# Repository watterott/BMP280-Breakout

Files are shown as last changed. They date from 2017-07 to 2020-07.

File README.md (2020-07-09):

# BMP280-Breakout
Breakout with BMP280 Digital Absolute Barometric Pressure Sensor from Bosch Sensortec.

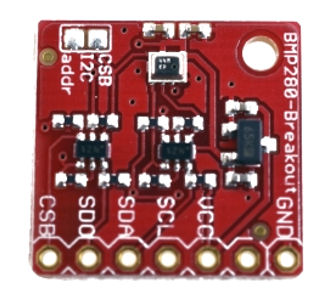
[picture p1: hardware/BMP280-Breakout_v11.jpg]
BMP280-Breakout


* [Bosch BMP280](https://www.bosch-sensortec.com/bst/products/all_products/bmp280) Absolute Barometric Pressure Sensor
* Pressure Range: 300...1100hPa (+9000...-500m above/below sea level)
* On-board 1.8V voltage regulator
* SPI Interface (up to 10MHz)
* TWI/I2C Interface (address 0x76 when SDO=0 or 0x77 when SDO=1, CS=1 for I2C)
* 3.3V - 5V Power Supply and Logic Level
* Open-Source and released under the [Creative Commons Attribution Share-Alike License](https://creativecommons.org/licenses/by-sa/4.0/).
* **[Documentation on learn.watterott.com](https://learn.watterott.com)**

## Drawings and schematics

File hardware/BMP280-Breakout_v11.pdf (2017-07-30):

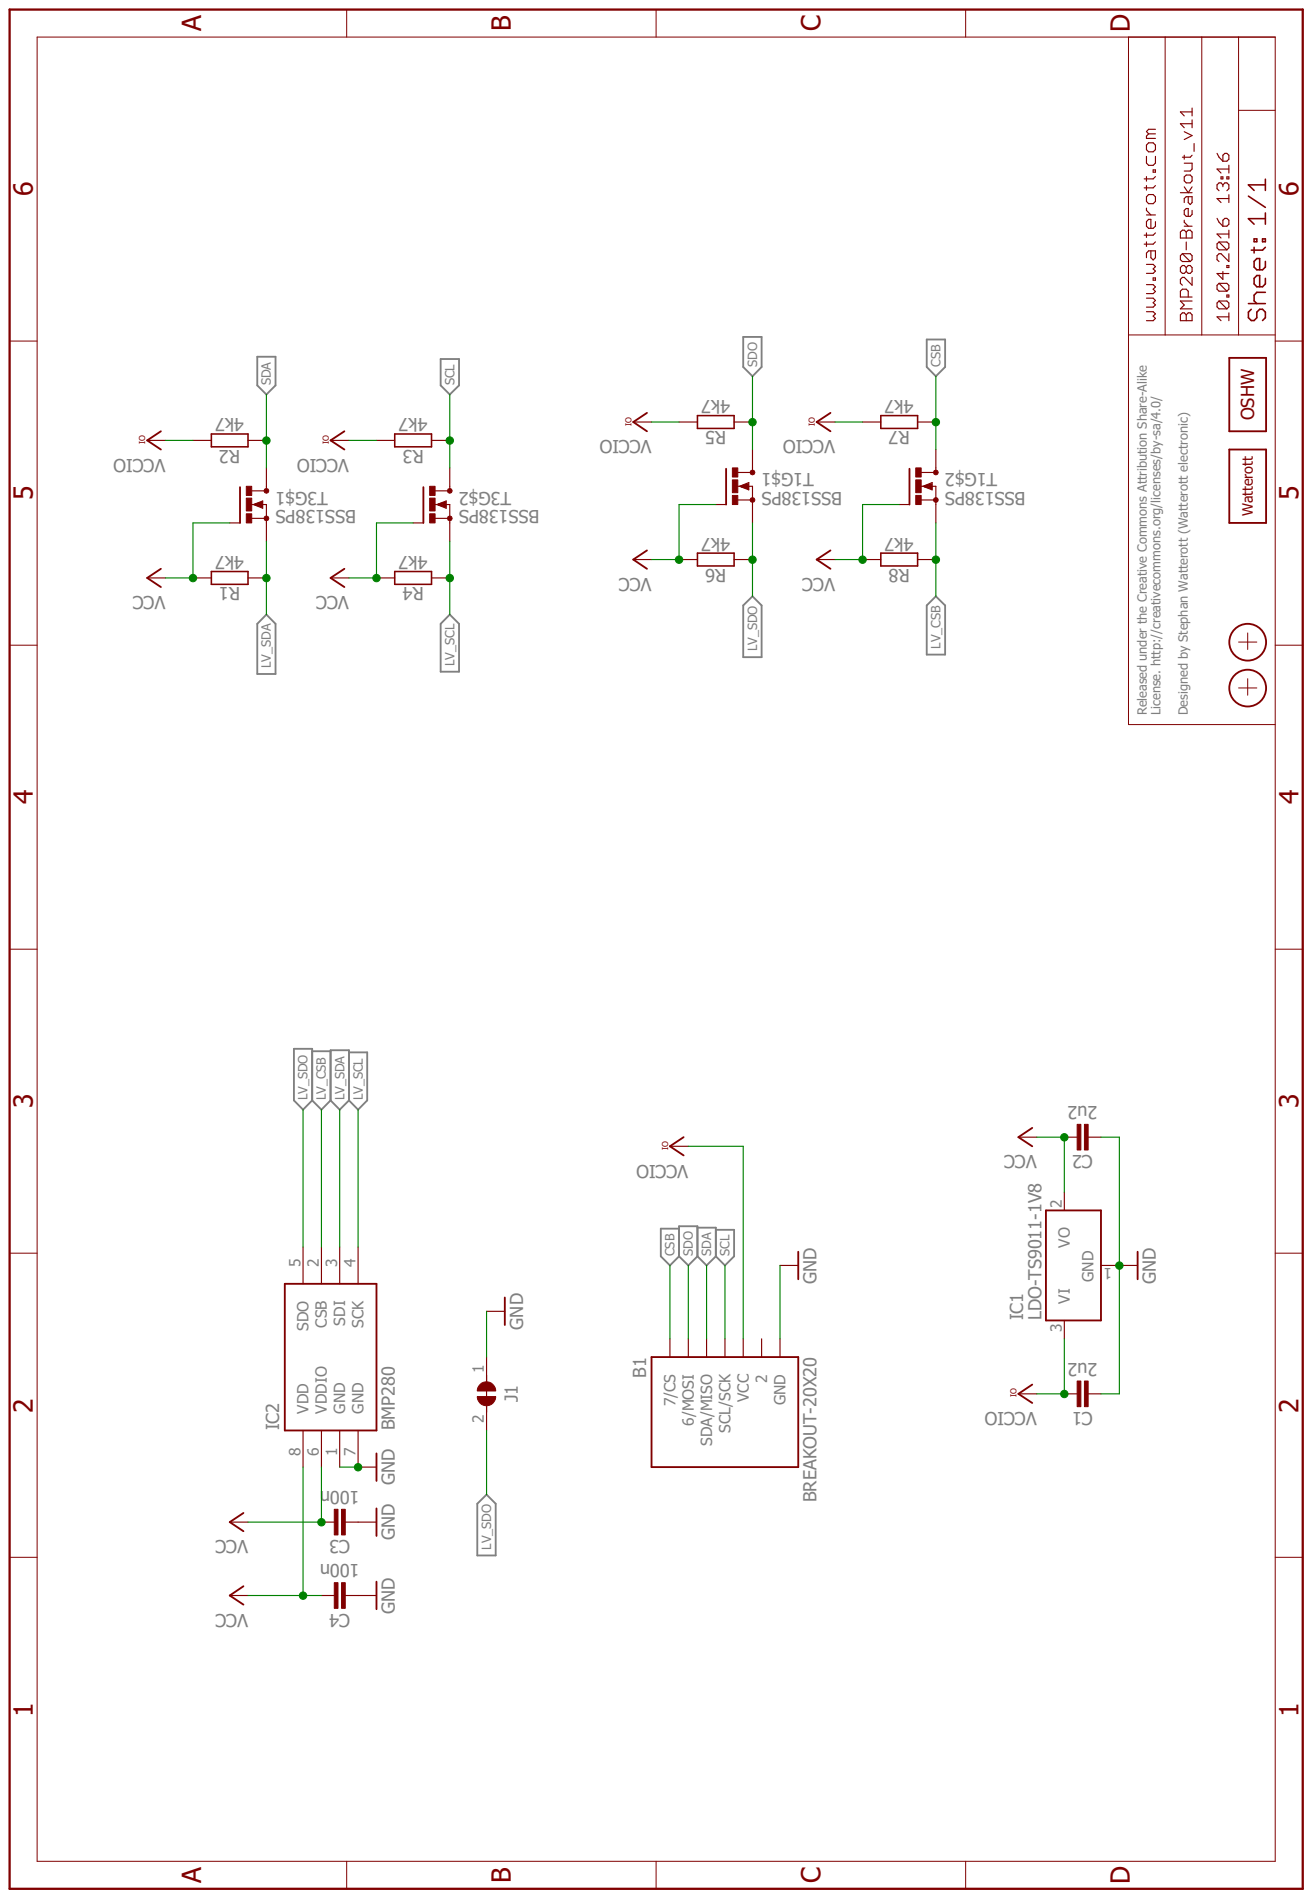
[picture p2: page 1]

Released under the Creative Commons Attribution Share-Alike

License. http://creativecommons.org/licenses/by-sa/4.0/ Designed by Stephan Watterott (Watterott electronic)

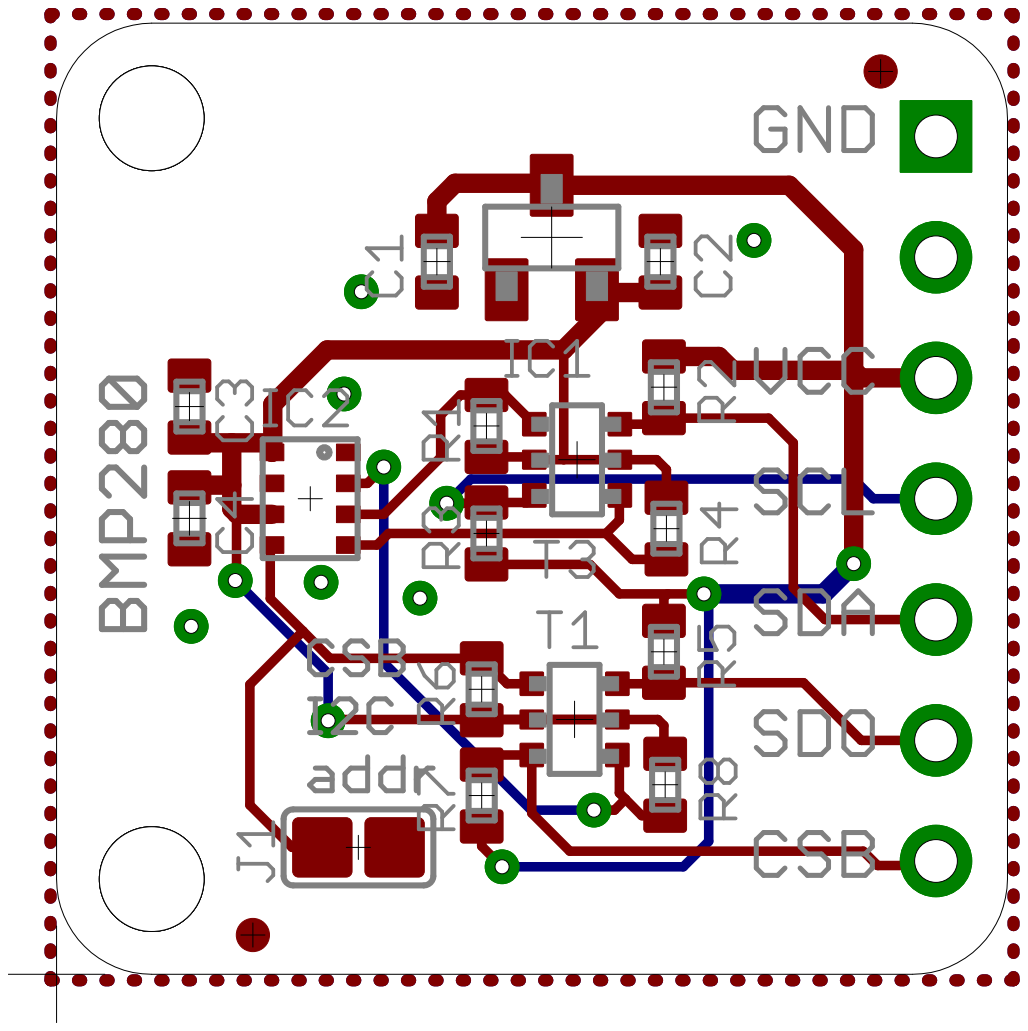
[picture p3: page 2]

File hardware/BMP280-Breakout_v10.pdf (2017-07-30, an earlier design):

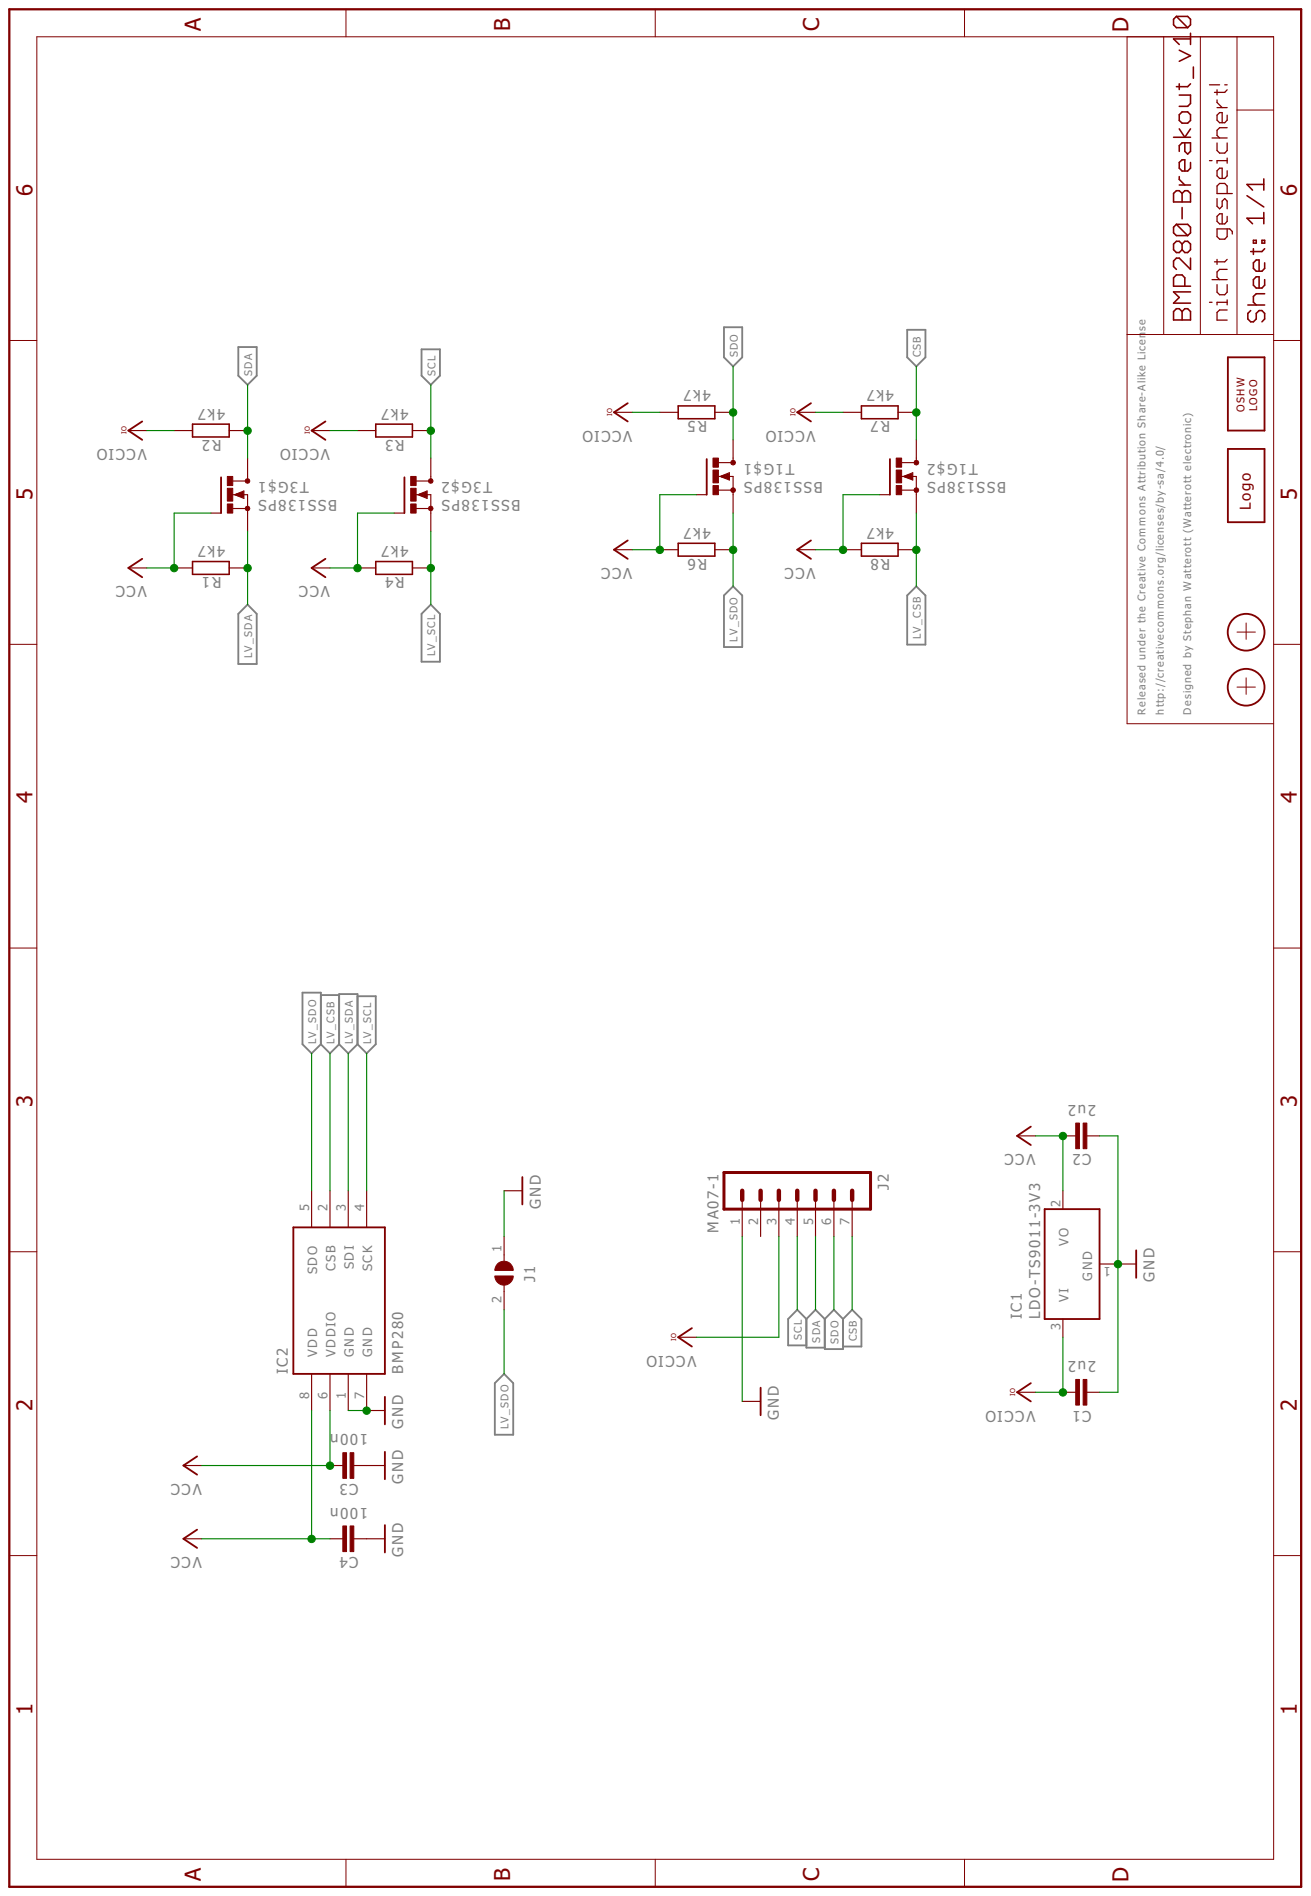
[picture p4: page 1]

Released under the Creative Commons Attribution Share-Alike License

Logo O SHW LO GO

Designed by Stephan Watterott (Watterott electronic)

http://creativecommons.org/licenses/by-sa/4.0/

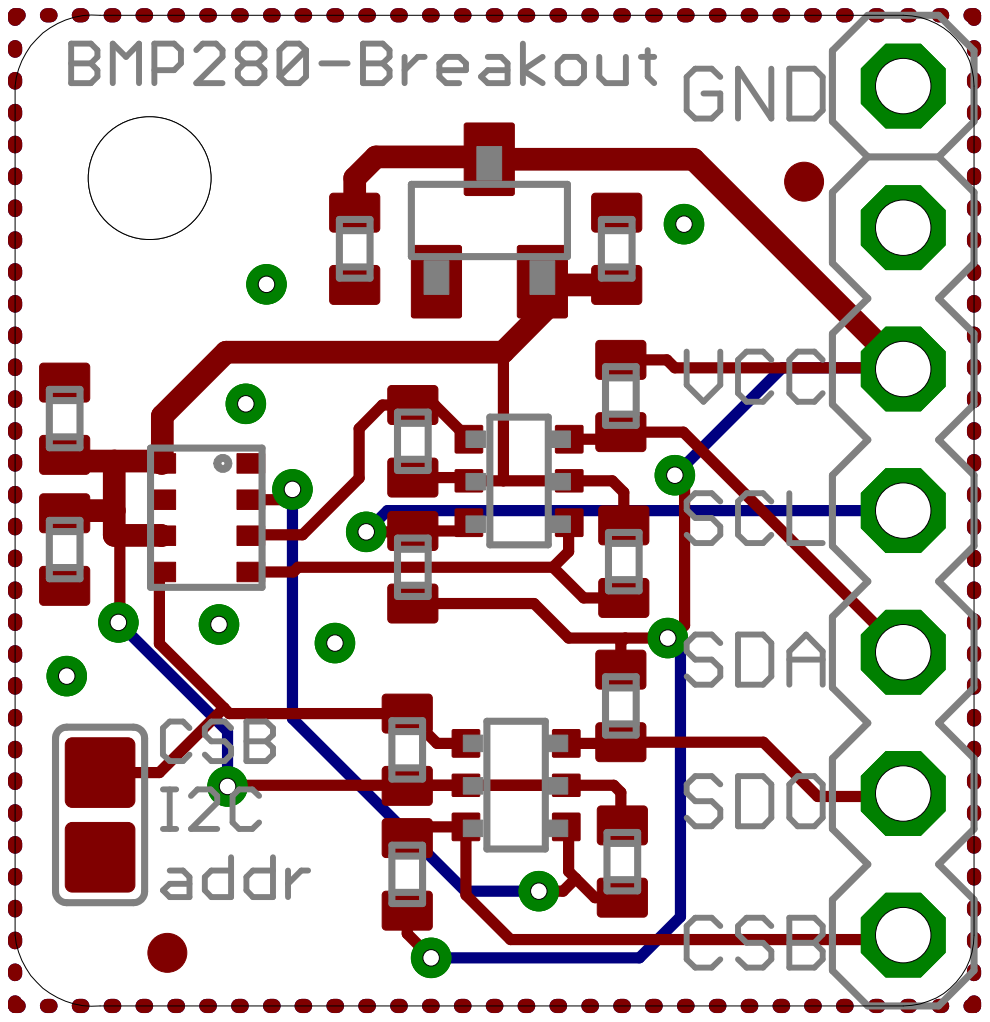
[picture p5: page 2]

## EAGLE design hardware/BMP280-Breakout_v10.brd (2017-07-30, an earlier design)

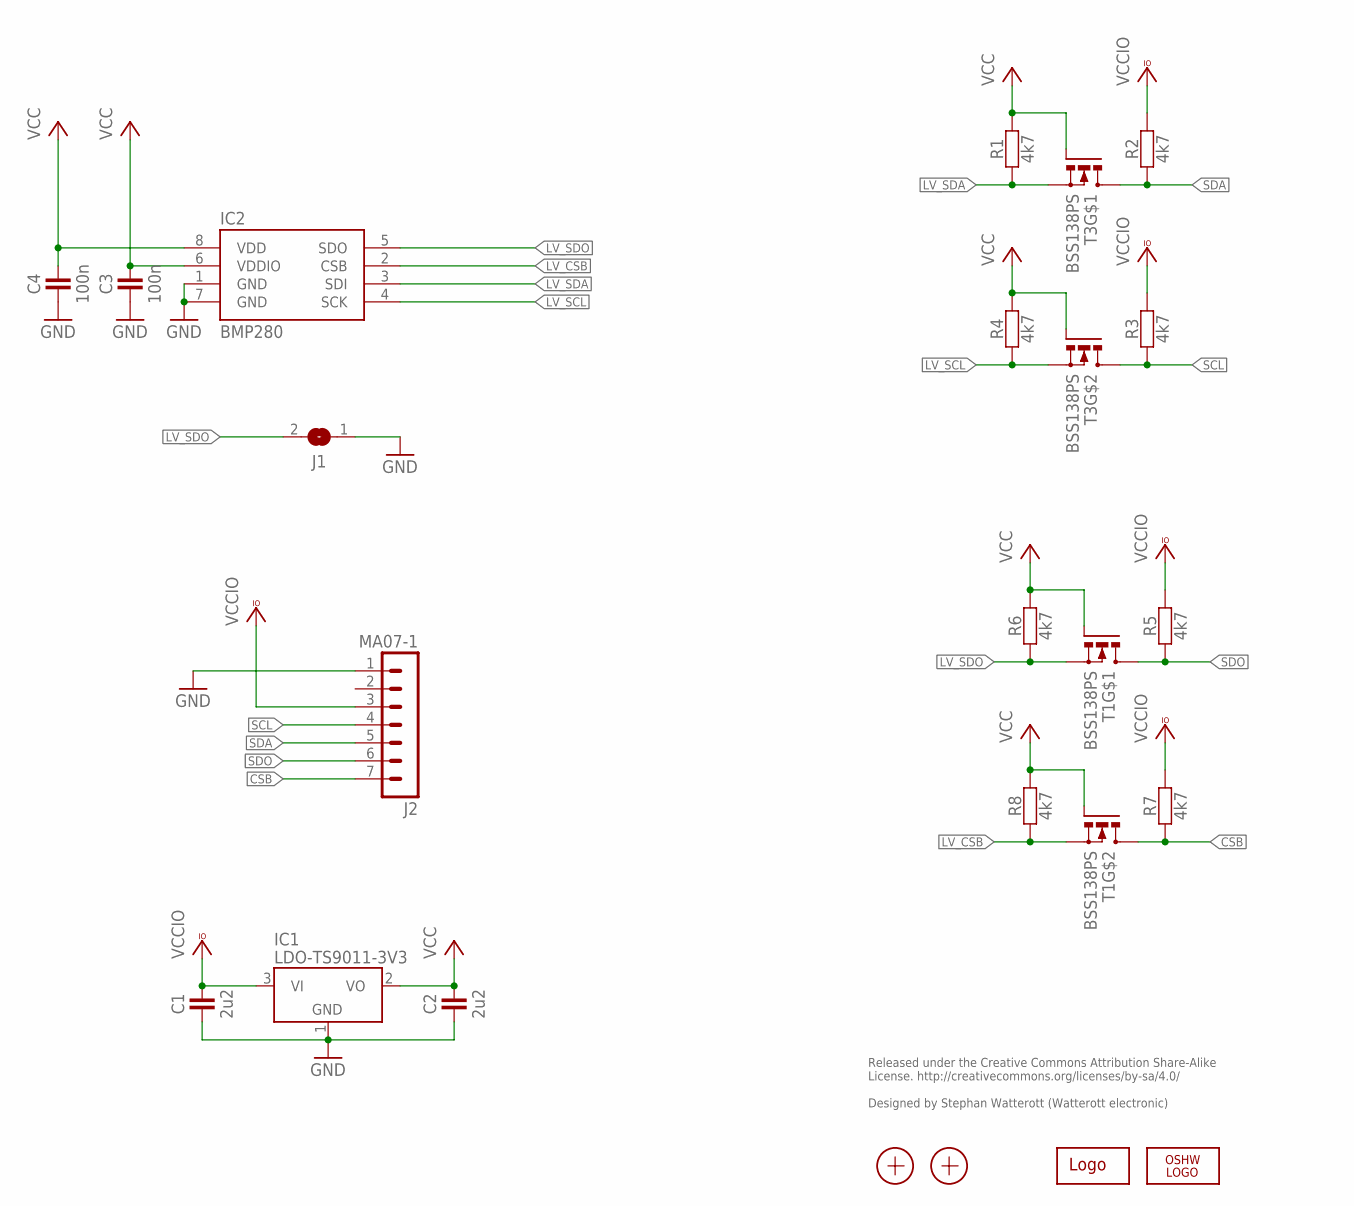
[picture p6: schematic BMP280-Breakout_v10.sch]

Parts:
C1, C2: 2u2; R0402
C3, C4: 100n; R0402
IC1: LDO-TS9011-3V3; SOT23
IC2: BMP280; LGA
J1: JUMPER2
J2: MA07-1
LOGO1: LOGO-S_PLACE_M; SPARK_TPLACE_M
LOGO2: OSHW_LOGOX0070; OSHW_6X70
R1, R2, R3, R4, R5, R6, R7, R8: 4k7; R0402
T1, T3: BSS138PS; SOT363
X1, X2: PASSER-07; PASSER_07MM

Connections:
CSB: J2.7, R7.1, T1.3 (D)
GND: C1.1, C2.1, C3.1, C4.1, IC1.1 (GND), IC2.1 (GND), IC2.7 (GND), J1.1, J2.1
LV_CSB: IC2.2 (CSB), R8.1, T1.4 (S)
LV_SCL: IC2.4 (SCK), R4.1, T3.4 (S)
LV_SDA: IC2.3 (SDI), R1.1, T3.1 (S)
LV_SDO: IC2.5 (SDO), J1.2, R6.1, T1.1 (S)
SCL: J2.4, R3.1, T3.3 (D)
SDA: J2.5, R2.1, T3.6 (D)
SDO: J2.6, R5.1, T1.6 (D)
VCC: C2.2, C3.2, C4.2, IC1.2 (VO), IC2.6 (VDDIO), IC2.8 (VDD), R1.2, R4.2, R6.2, R8.2, T1.2 (G), T1.5 (G), T3.2 (G), T3.5 (G)
VCCIO: C1.2, IC1.3 (VI), J2.3, R2.2, R3.2, R5.2, R7.2

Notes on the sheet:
Released under the Creative Commons Attribution Share-Alike License. http://creativecommons.org/licenses/by-sa/4.0/ Designed by Stephan Watterott (Watterott electronic)

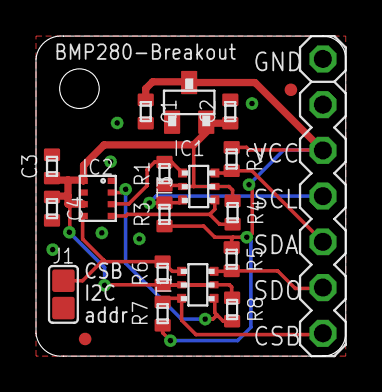
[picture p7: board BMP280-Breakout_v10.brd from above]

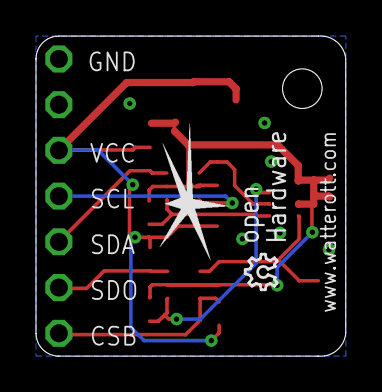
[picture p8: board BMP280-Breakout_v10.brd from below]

Board: 2 copper layers, 17.2 x 17.8 mm, 22 parts (2 on the bottom side), 11 nets.
